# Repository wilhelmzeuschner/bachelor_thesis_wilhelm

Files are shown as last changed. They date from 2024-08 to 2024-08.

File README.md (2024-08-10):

# Bachelor Thesis Wilhelm Zeuschner
This repo contains select files of my bachelor thesis

More details can be found on my website where I wrote an article about my thesis.

www.wizeus.de/lmm-ba

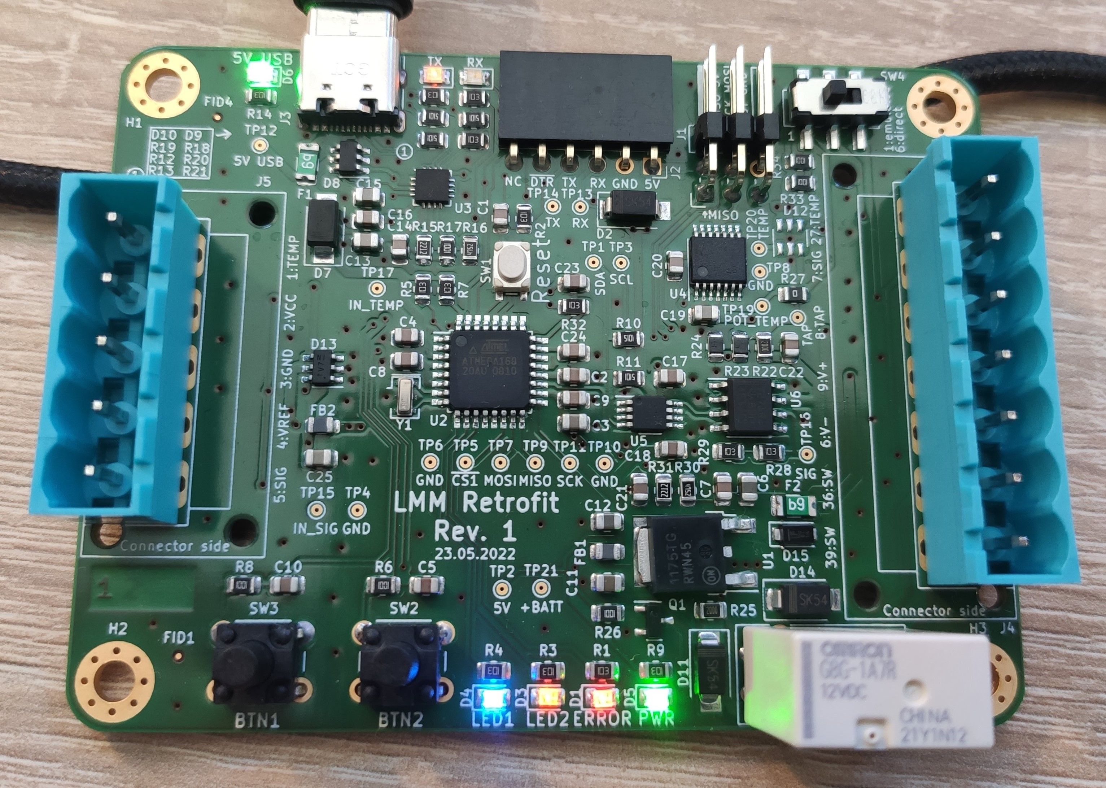
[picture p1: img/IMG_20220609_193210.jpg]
PCB picture


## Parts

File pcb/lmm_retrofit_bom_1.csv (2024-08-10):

Component | Description | Part | References | Value | Footprint | Quantity Per PCB | Datasheet | Digi-Key Part Number | MPN | Color | DNF | Info
1 | Unpolarized capacitor, small symbol | C_Small | C1 C2 C4 C5 C7 C8 C9 C10 C14 C16 C17 C18 C20 C21 C22 C23 C24 | 100nF | C_0805_2012Metric | 17 | https://www.yuden.co.jp/productdata/catalog/mlcc_all_hq_e.pdf | 587-3508-1-ND | UMK212B7104KGHT
2 | Unpolarized capacitor, small symbol | C_Small | C3 C6 C11 C12 C13 C15 C19 C25 | 10uF | C_0805_2012Metric | 8 | https://ds.yuden.co.jp/TYCOMPAS/ut/detail?pn=MCAST21GBB5106MTNA01&u=M | 587-6440-1-ND | TMK212BBJ106MGHT
3 | Light emitting diode, small symbol | LED_Small | D6 | 5V USB | LED_0805_2012Metric_Silkscreen_Text | 1 | https://www.we-online.com/katalog/datasheet/150080GS75000.pdf | 732-4983-1-ND | 150080GS75000 | Green
4 | Schottky diode, small symbol | D_Schottky_Small | D2 D7 D11 D14 | CDBA540-HF | D_SMA | 4 | https://media.digikey.com/pdf/Data%20Sheets/Comchip%20PDFs/CDBA540-HF-CDBA5200-HF_RevC.pdf | 641-1707-1-ND | CDBA540-HF
5 | 12V Clamp 3A (8/20µs) Ipp Tvs Diode Surface Mount SOT-26 | D5V0F4U6SO-7 | D12 D13 | D5V0F4U6SO-7 | SOT-23-6 | 2 | https://www.diodes.com/assets/Datasheets/D5V0F4U6SO.pdf | D5V0F4U6SO-7DICT-ND | D5V0F4U6SO-7
6 | 14V Clamp 7A (8/20µs) Ipp Tvs Diode Surface Mount SOT-26 | DM1231 | D8 | DM1231 | SOT-23-6 | 1 | https://media.digikey.com/pdf/Data%20Sheets/Diodes%20PDFs/DM1231-02SO.pdf | DM1231-02SO-7DICT-ND | DM1231-02SO-7
7 | Light emitting diode, small symbol | LED_Small | D1 | ERROR | LED_0805_2012Metric_Silkscreen_Text | 1 | https://www.we-online.com/katalog/datasheet/150080RS75000.pdf | 732-4984-1-ND | 150080RS75000 | Red
8 | Light emitting diode, small symbol | LED_Small | D4 | LED1 | LED_0805_2012Metric_Silkscreen_Text | 1 | https://www.we-online.com/katalog/datasheet/150080BS75000.pdf | 732-4982-1-ND | 150080BS75000 | Blue
9 | Light emitting diode, small symbol | LED_Small | D3 | LED2 | LED_0805_2012Metric_Silkscreen_Text | 1 | https://www.mouser.de/datasheet/2/445/150080AS75000-1879102.pdf | 732-150080AS75000CT-ND | 150080AS75000 | Amber
10 | Light emitting diode, small symbol | LED_Small | D5 | PWR | LED_0805_2012Metric_Silkscreen_Text | 1 | https://www.we-online.com/katalog/datasheet/150080GS75000.pdf | 732-4983-1-ND | 150080GS75000 | Green
11 | Light emitting diode, small symbol | LED_Small | D9 | RX | LED_0805_2012Metric_Silkscreen_Text | 1 | https://www.we-online.com/katalog/datasheet/150080BS75000.pdf | 732-4982-1-ND | 150080BS75000 | Blue
12 | Zener diode, small symbol | D_Zener_Small | D15 | SMF18A | D_SOD-123F | 1 | https://www.littelfuse.com/~/media/electronics/datasheets/tvs_diodes/littelfuse_tvs_diode_smf_datasheet.pdf.pdf | F5820CT-ND | SMF18A
13 | Light emitting diode, small symbol | LED_Small | D10 | TX | LED_0805_2012Metric_Silkscreen_Text | 1 | https://www.mouser.de/datasheet/2/445/150080AS75000-1879102.pdf | 732-150080AS75000CT-ND | 150080AS75000 | Amber
14 | Resettable fuse, polymeric positive temperature coefficient | Polyfuse | F1 F2 | 250mA | Fuse_1206_3216Metric | 2 | https://www.belfuse.com/resources/datasheets/circuitprotection/ds-cp-0zcj-series.pdf | 507-1799-1-ND | 0ZCJ0025AF2E
15 | Ferrite bead, small symbol | FerriteBead_Small | FB1 FB2 | 1k@100MHz | L_0805_2012Metric | 2 | https://abracon.com/Magnetics/new/ACML-0805.pdf | 535-ACML-0805-102-TCT-ND | ACML-0805-102-T
16 | Hot-film air-mass meter, Type HFM 5 | Bosch_HFM5_LMM | J5 | Bosch_HFM5_LMM | Bosch_Airmass_Senosor_5-Pin_Male_Blade_Connector | 1 | https://mux.hs-emden-leer.de/svn/micro-projects-lmm/30_datasheets/LMM/HFM5_Datenblatt.pdf |  | 0 280 217 531 |  | Do not fit
17 | Airflow meter for L Jetronic ECUs; Luftmengenmesser für Oldtimer | Bosch_old_LMM | J4 | Bosch_old_LMM | Bosch_L_Jetronic_7-Pin_Male_Blade_Conn | 1 | https://mux.hs-emden-leer.de/svn/micro-projects-lmm/30_datasheets/L_Jetronic/_tr7_ecu.pdf |  | 0 280 203 002 |  | Do not fit
18 | Generic connector, double row, 02x03, odd/even pin numbering scheme (row 1 odd numbers, row 2 even numbers), script generated (kicad-library-utils/schlib/autogen/connector/) | Conn_02x03_Odd_Even | J1 | ICSP | PinHeader_2x03_P2.54mm_Horizontal | 1 | https://app.adam-tech.com/products/download/data_sheet/200508/ph2ra-xx-ua-data-sheet.pdf | 2057-PH2RA-06-UA-ND | PH2RA-06-UA
19 | Generic connector, single row, 01x06, script generated (kicad-library-utils/schlib/autogen/connector/) | Conn_01x06_Female | J2 | PC | PinSocket_1x06_P2.54mm_Horizontal | 1 | https://media.metz-connect.com/files/171/Data_sheet_FR202XXHBNN.PDF | 1849-FR20206HBNN-ND | FR20206HBNN
20 | USB 2.0-only Type-C Receptacle connector | USB_C_Receptacle_USB2.0 | J3 | USB_C_Receptacle_USB2.0 | USB_C_Receptacle_GCT_USB4105-GF-A | 1 | https://gct.co/files/drawings/usb4105.pdf | 2073-USB4105-GF-ACT-ND | USB4105-GF-A
21 | AUTO MOTIVE PCB RELAY, DC 12V | G8G | K1 | G8G | G8G__SPST | 1 | https://components.omron.com/us-en/datasheet_pdf/J263-E1.pdf | 39-G8G-1A7RDC12BYOMR1-ND | G8G-1A7R DC12 BY OMR1
22 | NPN transistor, base/emitter/collector | Q_NPN_BEC | Q1 | MMBT4401-7-F | SOT-23 | 1 | https://www.comchiptech.com/admin/files/product/QW-JTR91%20MMBT4401-HF%20RevB.pdf | 641-MMBT4401-HFCT-ND | MMBT4401-HF
23 | Resistor, small symbol | R_Small | R27 | 0R | R_0805_2012Metric | 1 | https://www.yageo.com/upload/media/product/productsearch/datasheet/rchip/PYu-AC_51_RoHS_L_8.pdf | YAG3755CT-ND | AC0805JR-070RL |  |  | Populate with value >0R if voltage on A pin would be too high.
24 | Resistor, small symbol | R_Small | R23 R24 | 182 | R_0805_2012Metric | 2 | https://www.vishay.com/docs/20035/dcrcwe3.pdf | 541-182CCT-ND | CRCW0805182RFKEA
25 | Resistor, small symbol | R_Small | R22 R25 | 200 | R_0805_2012Metric | 2 | https://fscdn.rohm.com/en/products/databook/datasheet/passive/resistor/chip_resistor/esr-e.pdf | RHM200AECT-ND | ESR10EZPF2000
26 | Resistor, small symbol | R_Small | R6 R8 R17 R26 R33 R34 | 1k | R_0805_2012Metric | 6 | https://www.te.com/commerce/DocumentDelivery/DDEController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 | A129749CT-ND | CRGCQ0805F1K0
27 | Resistor, small symbol | R_Small | R10 R11 R12 R13 R20 | 5.1k | R_0805_2012Metric | 5 | https://www.te.com/commerce/DocumentDelivery/DDEController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 | A126379CT-ND | CRG0805F5K1
28 | Resistor, small symbol | R_Small | R1 R2 R3 R4 R5 R7 R9 R14 R18 R19 R21 R28 R29 R32 | 10k | R_0805_2012Metric | 14 | https://www.te.com/commerce/DocumentDelivery/DDEController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 | A130140CT-ND | CRGCQ0805J10K
29 | Resistor, small symbol | R_Small | R15 R31 | 22.1k | R_0805_2012Metric | 2 | https://www.bourns.com/docs/product-datasheets/cr.pdf?sfvrsn=574d41f6_14 | CR0805-FX-2212ELFCT-ND | CR0805-FX-2212ELF
30 | Resistor, small symbol | R_Small | R16 R30 | 47.5k | R_0805_2012Metric | 2 | https://www.bourns.com/docs/product-datasheets/cr.pdf?sfvrsn=574d41f6_14 | 118-CR0805-FX-4752ELFCT-ND | CR0805-FX-4752ELF
31 | Push button switch, generic, two pins | SW_Push | SW3 | BTN1 | SW_PUSH_6mm_H9.5mm | 1 | https://www.cuidevices.com/product/resource/ts03.pdf | 2223-TS03-66-95-BK-260-LCR-D-67-ND | TS03-66-95-BK-260-LCR-D-67
32 | Push button switch, generic, two pins | SW_Push | SW2 | BTN2 | SW_PUSH_6mm_H9.5mm | 1 | https://www.cuidevices.com/product/resource/ts03.pdf | 2223-TS03-66-95-BK-260-LCR-D-67-ND | TS03-66-95-BK-260-LCR-D-67
33 | Push button switch, four pins, both channels connected | CKN12216-1-ND | SW1 | Reset | PTS815_SMT_Push_Button | 1 | https://www.ckswitches.com/media/2728/pts815.pdf | CKN12216-1-ND | PTS815 SJK 250 SMTR LFS
34 | Switch, dual pole double throw, separate symbols | SW_DPDT_x2 | SW4 | Thermistor select | JS202011SCQN | 1 | https://www.ckswitches.com/media/1422/js.pdf | 401-2002-1-ND | JS202011SCQN
35 | Digital potentiometer, 256 position, single output, I2C interface | AD5280 | U4 | AD5280 | TSSOP-14_4.4x5mm_P0.65mm | 1 | https://www.analog.com/media/en/technical-documentation/data-sheets/AD5280_5282.pdf | AD5280BRUZ50-ND | AD5280BRUZ50
36 | 20MHz, 16kB Flash, 1kB SRAM, 512B EEPROM, TQFP-32 | ATmega168-20A | U2 | ATmega168-20A | TQFP-32_7x7mm_P0.8mm | 1 | http://ww1.microchip.com/downloads/en/DeviceDoc/Atmel-2545-8-bit-AVR-Microcontroller-ATmega48-88-168_Datasheet.pdf | ATMEGA168-20AU-ND | ATMEGA168-20AU
37 | USB to UART master bridge, QFN-20 | CP2102N-Axx-xQFN20 | U3 | CP2102N-A02-GQFN20 | SiliconLabs_QFN-20-1EP_3x3mm_P0.5mm_EP1.8x1.8mm_Center_Via | 1 | https://www.silabs.com/documents/public/data-sheets/cp2102n-datasheet.pdf | 336-5885-ND | CP2102N-A02-GQFN20
38 | 10 Bit Digital to Analog Converter 1 8-VSSOP | DAC101C085CIMM{slash}NOPB | U5 | DAC101C085CIMM/NOPB | VSSOP-8_3.0x3.0mm_P0.65mm | 1 | http://www.ti.com/lit/ds/symlink/dac101c081.pdf | DAC101C085CIMM/NOPBCT-ND | DAC101C085CIMM/NOPB
39 | 1A Low drop-out regulator, Fixed Output 5.0V, TO-252 (DPAK) | NCP1117-5.0_TO252 | U1 | NCP1117IDT50T4G | TO-252-2 | 1 | https://www.onsemi.com/pdf/datasheet/ncp1117-d.pdf | 488-NCP1117IDT50T4GCT-ND | NCP1117IDT50T4G
40 | General Purpose Amplifier 1 Circuit Rail-to-Rail 8-SOIC | TLV271 | U6 | TLV271 | SOIC-8_3.9x4.9mm_P1.27mm | 1 | https://www.ti.com/general/docs/suppproductinfo.tsp?distId=10 | 296-38281-1-ND | TLV271QDRQ1
41 | Three pin ceramic resonator, small symbol | Resonator_Small | Y1 | 16MHz | Resonator_SMD_Murata_CSTxExxV-3Pin_3.0x1.1mm | 1 | https://www.murata.com/en/products/productdata/8801162231838/SPEC-CSTNE16M0V530000R0.pdf | 490-17948-1-ND | CSTNE16M0V530000R0
Component Groups: | 41
Component Count: | 96
Fitted Components: | 96
Number of PCBs: | 1
Total components: | 96
Schematic Version: | 1
Schematic Date: | 2022-05-08
PCB Variant: | default
BoM Date: | 22/05/2022 21:42:45
Schematic Source: | lmm_retrofit.kicad_sch
KiCad Version: | Eeschema (6.0.5)

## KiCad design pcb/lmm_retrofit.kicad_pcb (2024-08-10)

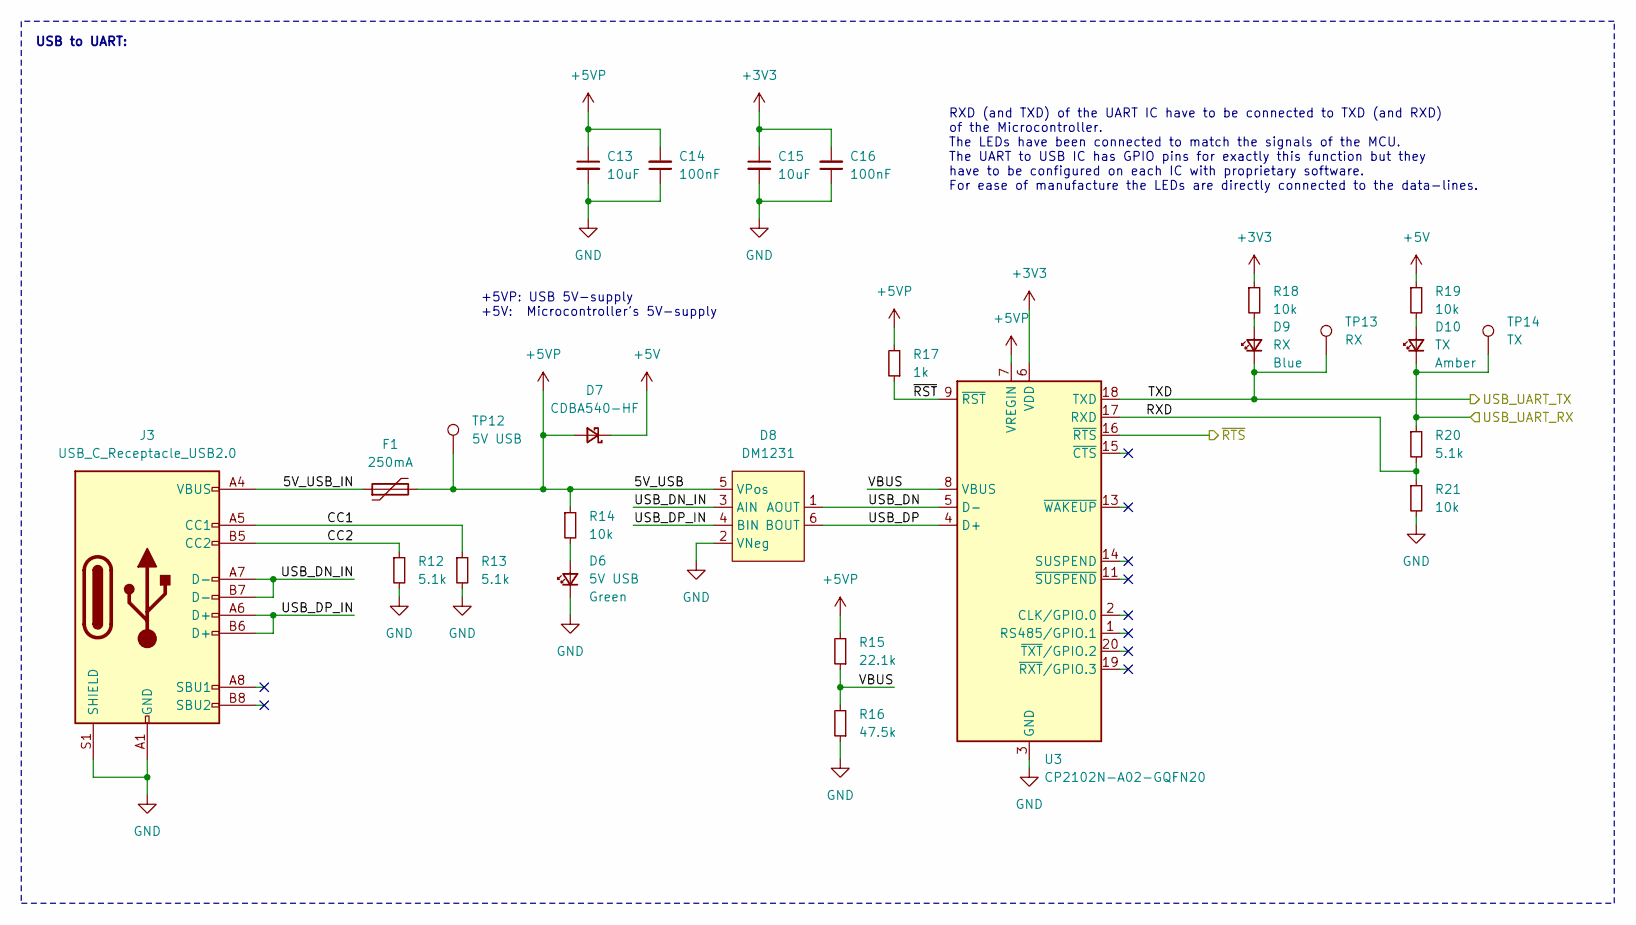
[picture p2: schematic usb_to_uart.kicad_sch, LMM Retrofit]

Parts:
C13, C15: 10uF; C_0805_2012Metric; MPN TMK212BBJ106MGHT; Digi-Key Part Number 587-6440-1-ND
C14, C16: 100nF; C_0805_2012Metric; MPN UMK212B7104KGHT; Digi-Key Part Number 587-3508-1-ND
D6: 5V USB; LED_0805_2012Metric_Silkscreen_Text; MPN 150080GS75000; Digi-Key Part Number 732-4983-1-ND
D7: CDBA540-HF; D_SMA; MPN CDBA540-HF; Digi-Key Part Number 641-1707-1-ND
D8: DM1231; SOT-23-6; MPN DM1231-02SO-7; Digi-Key Part Number DM1231-02SO-7DICT-ND
D9: RX; LED_0805_2012Metric_Silkscreen_Text; MPN 150080BS75000; Digi-Key Part Number 732-4982-1-ND
D10: TX; LED_0805_2012Metric_Silkscreen_Text; MPN 150080AS75000; Digi-Key Part Number 732-150080AS75000CT-ND
F1: 250mA; Fuse_1206_3216Metric; MPN 0ZCJ0025AF2E; Digi-Key Part Number 507-1799-1-ND
J3: USB_C_Receptacle_USB2.0; USB_C_Receptacle_GCT_USB4105-GF-A; MPN USB4105-GF-A; Digi-Key Part Number 2073-USB4105-GF-ACT-ND
R12, R13, R20: 5.1k; R_0805_2012Metric; MPN CRG0805F5K1; Digi-Key Part Number A126379CT-ND
R14, R18, R19, R21: 10k; R_0805_2012Metric; MPN CRGCQ0805J10K; Digi-Key Part Number A130140CT-ND
R15: 22.1k; R_0805_2012Metric; MPN CR0805-FX-2212ELF; Digi-Key Part Number CR0805-FX-2212ELFCT-ND
R16: 47.5k; R_0805_2012Metric; MPN CR0805-FX-4752ELF; Digi-Key Part Number 118-CR0805-FX-4752ELFCT-ND
R17: 1k; R_0805_2012Metric; MPN CRGCQ0805F1K0; Digi-Key Part Number A129749CT-ND
TP12: 5V USB; TestPoint_Pad_D1.0mm_Text_Silkscreen
TP13: RX; TestPoint_Pad_D1.0mm_Text_Silkscreen
TP14: TX; TestPoint_Pad_D1.0mm_Text_Silkscreen
U3: CP2102N-A02-GQFN20; SiliconLabs_QFN-20-1EP_3x3mm_P0.5mm_EP1.8x1.8mm_Center_Via; MPN CP2102N-A02-GQFN20; Digi-Key Part Number 336-5885-ND

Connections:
+3V3: C15.1, C16.2, R18.1, U3.6 (VDD)
+5V: D7.1 (K), R19.1; also elsewhere on the board
+5VP: C13.1, C14.2, D7.2 (A), D8.5 (VPos), F1.2, R14.1, R15.2, R17.2, TP12.1, U3.7 (VREGIN)
/Microcontroller/D0/UART_RX: D9.1 (K), TP13.1, U3.18 (TXD); also elsewhere on the board
/Microcontroller/D1/UART_TX: D10.1 (K), R20.1, TP14.1; also elsewhere on the board
/Microcontroller/~DTR: U3.16 (~RTS); also elsewhere on the board
/USB to UART/5V_USB_IN: F1.1, J3.A4 (VBUS), J3.A9 (VBUS), J3.B4 (VBUS), J3.B9 (VBUS)
/USB to UART/CC1: J3.A5 (CC1), R13.1
/USB to UART/CC2: J3.B5 (CC2), R12.1
/USB to UART/RXD: R20.2, R21.1, U3.17 (RXD)
/USB to UART/USB_DN: D8.1 (AOUT), U3.5 (D-)
/USB to UART/USB_DN_IN: D8.3 (AIN), J3.A7 (D-), J3.B7 (D-)
/USB to UART/USB_DP: D8.6 (BOUT), U3.4 (D+)
/USB to UART/USB_DP_IN: D8.4 (BIN), J3.A6 (D+), J3.B6 (D+)
/USB to UART/VBUS: R15.1, R16.2, U3.8 (VBUS)
/USB to UART/~RST: R17.1, U3.9 (~RST)
unnamed: D6.2 (A), R14.2
unnamed: D9.2 (A), R18.2
unnamed: D10.2 (A), R19.2

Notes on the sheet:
+5VP: USB 5V-supply +5V: Microcontroller's 5V-supply
USB to UART:
RXD (and TXD) of the UART IC have to be connected to TXD (and RXD) of the Microcontroller. The LEDs have been connected to match the signals of the MCU. The UART to USB IC has GPIO pins for exactly this function but they have to be configured on each IC with proprietary software. For ease of manufa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

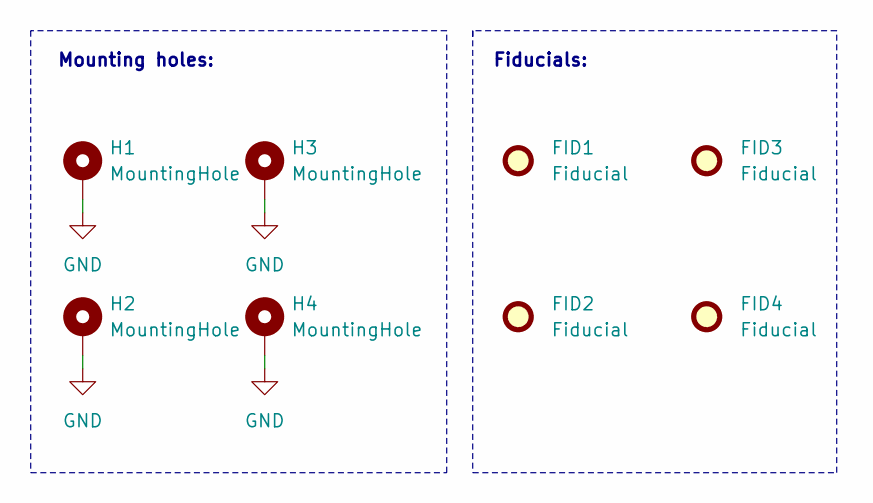
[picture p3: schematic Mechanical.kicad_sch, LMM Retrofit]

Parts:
FID1, FID2, FID3, FID4: Fiducial; Fiducial_0.5mm_Mask1mm
H1, H2, H3, H4: MountingHole; MountingHole_3.2mm_M3_Pad_Via

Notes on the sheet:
Fiducials:
Mounting holes:

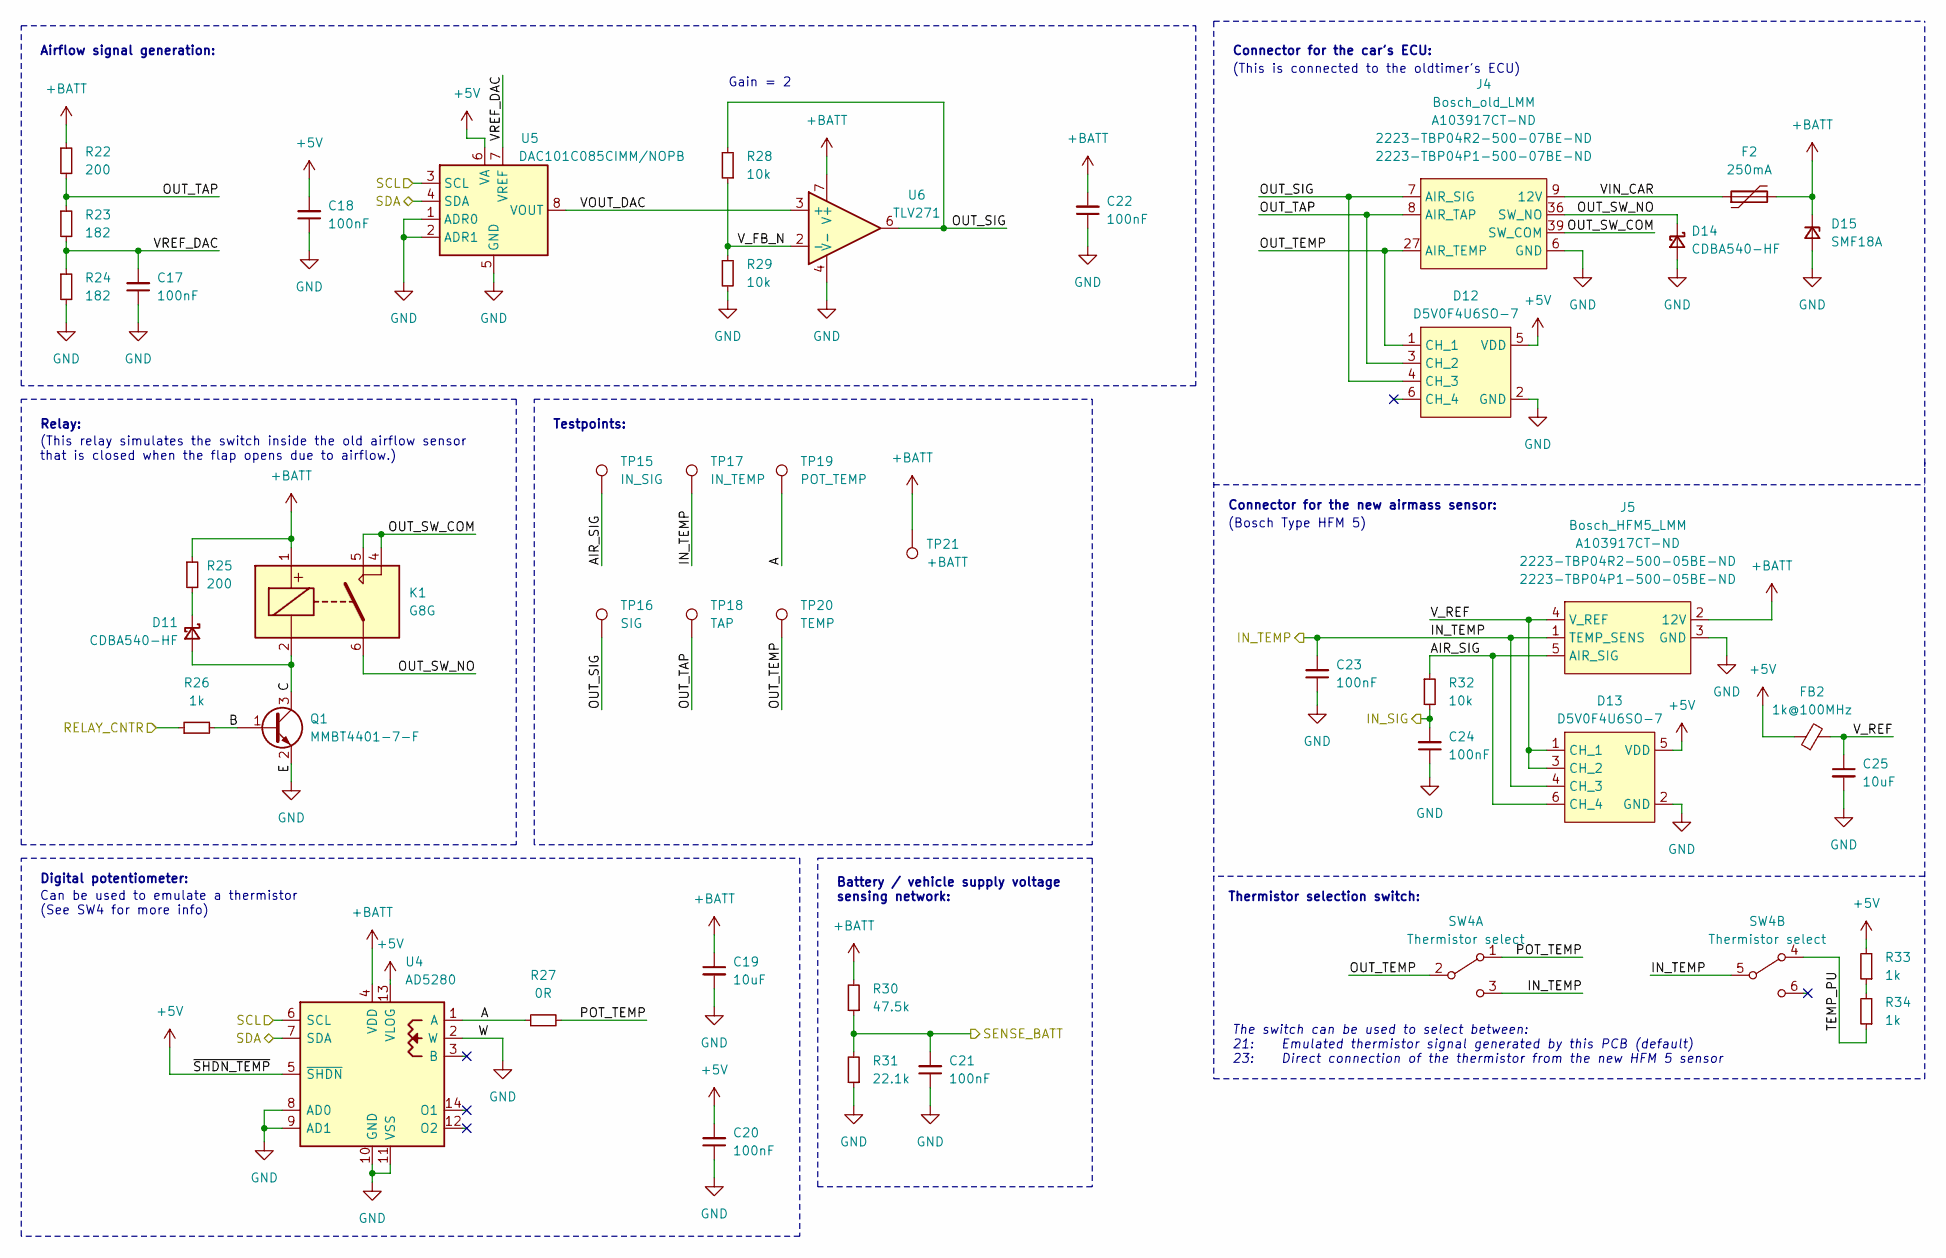
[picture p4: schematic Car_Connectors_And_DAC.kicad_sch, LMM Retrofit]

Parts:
C17, C18, C20, C21, C22, C23, C24: 100nF; C_0805_2012Metric; MPN UMK212B7104KGHT; Digi-Key Part Number 587-3508-1-ND
C19, C25: 10uF; C_0805_2012Metric; MPN TMK212BBJ106MGHT; Digi-Key Part Number 587-6440-1-ND
D11, D14: CDBA540-HF; D_SMA; MPN CDBA540-HF; Digi-Key Part Number 641-1707-1-ND
D12, D13: D5V0F4U6SO-7; SOT-23-6; MPN D5V0F4U6SO-7; Digi-Key Part Number D5V0F4U6SO-7DICT-ND
D15: SMF18A; D_SOD-123F; MPN SMF18A; Digi-Key Part Number F5820CT-ND
F2: 250mA; Fuse_1206_3216Metric; MPN 0ZCJ0025AF2E; Digi-Key Part Number 507-1799-1-ND
FB2: 1k@100MHz; L_0805_2012Metric; MPN ACML-0805-102-T; Digi-Key Part Number 535-ACML-0805-102-TCT-ND
J4: Bosch_old_LMM; Bosch_L_Jetronic_7-Pin_Male_Blade_Conn; MPN 0 280 203 002
J5: Bosch_HFM5_LMM; Bosch_Airmass_Senosor_5-Pin_Male_Blade_Connector; MPN 0 280 217 531
K1: G8G; G8G__SPST; MPN G8G-1A7R DC12 BY OMR1; Digi-Key Part Number 39-G8G-1A7RDC12BYOMR1-ND
Q1: MMBT4401-7-F; SOT-23; MPN MMBT4401-HF; Digi-Key Part Number 641-MMBT4401-HFCT-ND
R22, R25: 200; R_0805_2012Metric; MPN ESR10EZPF2000; Digi-Key Part Number RHM200AECT-ND
R23, R24: 182; R_0805_2012Metric; MPN CRCW0805182RFKEA; Digi-Key Part Number 541-182CCT-ND
R26, R33, R34: 1k; R_0805_2012Metric; MPN CRGCQ0805F1K0; Digi-Key Part Number A129749CT-ND
R27: 0R; R_0805_2012Metric; MPN AC0805JR-070RL; Digi-Key Part Number YAG3755CT-ND
R28, R29, R32: 10k; R_0805_2012Metric; MPN CRGCQ0805J10K; Digi-Key Part Number A130140CT-ND
R30: 47.5k; R_0805_2012Metric; MPN CR0805-FX-4752ELF; Digi-Key Part Number 118-CR0805-FX-4752ELFCT-ND
R31: 22.1k; R_0805_2012Metric; MPN CR0805-FX-2212ELF; Digi-Key Part Number CR0805-FX-2212ELFCT-ND
SW4: Thermistor select; JS202011SCQN; MPN JS202011SCQN; Digi-Key Part Number 401-2002-1-ND
TP15: IN_SIG; TestPoint_Pad_D1.0mm_Text_Silkscreen
TP16: SIG; TestPoint_Pad_D1.0mm_Text_Silkscreen
TP17: IN_TEMP; TestPoint_Pad_D1.0mm_Text_Silkscreen
TP18: TAP; TestPoint_Pad_D1.0mm_Text_Silkscreen
TP19: POT_TEMP; TestPoint_Pad_D1.0mm_Text_Silkscreen
TP20: TEMP; TestPoint_Pad_D1.0mm_Text_Silkscreen
TP21: +BATT; TestPoint_Pad_D1.0mm_Text_Silkscreen
U4: AD5280; TSSOP-14_4.4x5mm_P0.65mm; MPN AD5280BRUZ50; Digi-Key Part Number AD5280BRUZ50-ND
U5: DAC101C085CIMM/NOPB; VSSOP-8_3.0x3.0mm_P0.65mm; MPN DAC101C085CIMM/NOPB; Digi-Key Part Number DAC101C085CIMM/NOPBCT-ND
U6: TLV271; SOIC-8_3.9x4.9mm_P1.27mm; MPN TLV271QDRQ1; Digi-Key Part Number 296-38281-1-ND

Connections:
+5V: C18.2, C20.2, D12.5 (VDD), D13.5 (VDD), FB2.1, R33.2, U4.5 (~SHDN), U4.13 (VLOG), U5.6 (VA); also elsewhere on the board
+BATT: C19.1, C22.2, D15.1 (K), F2.2, J5.2 (12V), K1.1, R22.1, R25.1, R30.2, TP21.1, U4.4 (VDD), U6.7 (V+); also elsewhere on the board
/Car_Connectors_And_DAC/A: R27.1, TP19.1, U4.1 (A)
/Car_Connectors_And_DAC/AIR_SIG: D13.6 (CH_4), J5.5 (AIR_SIG), R32.1, TP15.1
/Car_Connectors_And_DAC/B: Q1.1 (B), R26.2
/Car_Connectors_And_DAC/C: D11.2 (A), K1.2, Q1.3 (C)
/Car_Connectors_And_DAC/IN_TEMP: C23.2, D13.4 (CH_3), J5.1 (TEMP_SENS), SW4.3 (C), SW4.5 (B), TP17.1; also elsewhere on the board
/Car_Connectors_And_DAC/OUT_SIG: D12.4 (CH_3), J4.7 (AIR_SIG), R28.2, TP16.1, U6.6
/Car_Connectors_And_DAC/OUT_SW_COM: J4.39 (SW_COM), K1.4, K1.5
/Car_Connectors_And_DAC/OUT_SW_NO: D14.1 (K), J4.36 (SW_NO), K1.6
/Car_Connectors_And_DAC/OUT_TAP: D12.3 (CH_2), J4.8 (AIR_TAP), R22.2, R23.1, TP18.1
/Car_Connectors_And_DAC/OUT_TEMP: D12.1 (CH_1), J4.27 (AIR_TEMP), SW4.2 (B), TP20.1
/Car_Connectors_And_DAC/POT_TEMP: R27.2, SW4.1 (A)
/Car_Connectors_And_DAC/TEMP_PU: R34.1, SW4.4 (A)
/Car_Connectors_And_DAC/VIN_CAR: F2.1, J4.9 (12V)
/Car_Connectors_And_DAC/VOUT_DAC: U5.8 (VOUT), U6.3 (+)
/Car_Connectors_And_DAC/VREF_DAC: C17.2, R23.2, R24.1, U5.7 (VREF)
/Car_Connectors_And_DAC/V_FB_N: R28.1, R29.1, U6.2 (-)
/Car_Connectors_And_DAC/V_REF: C25.1, D13.1 (CH_1), D13.3 (CH_2), FB2.2, J5.4 (V_REF)
/Microcontroller/A0/SIG: C24.2, R32.2; also elsewhere on the board
/Microcontroller/A4/SDA: U4.7 (SDA), U5.4 (SDA); also elsewhere on the board
/Microcontroller/A5/SCL: U4.6 (SCL), U5.3 (SCL); also elsewhere on the board
/Microcontroller/A6/BATT: C21.2, R30.1, R31.2; also elsewhere on the board
/Microcontroller/D4/RELAY: R26.1; also elsewhere on the board
unnamed: D11.1 (K), R25.2
unnamed: R33.1, R34.2

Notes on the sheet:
Testpoints:
Battery / vehicle supply voltage sensing network:
Connector for the car's ECU:
The switch can be used to select between: 21: Emulated thermistor signal generated by this PCB (default) 23: Direct connection of the thermistor from the new HFM 5 sensor
Digital potentiometer:
Thermistor selection switch:
(Bosch Type HFM 5)
Relay:
Airflow signal generation:
Connector for the new airmass sensor:
Gain = 2
(This relay simulates the switch inside the old airflow sensor that is closed when the flap opens due to airflow.)
(This is connected to the oldtimer's ECU)
Can be used to emulate a thermistor (See SW4 for more info)

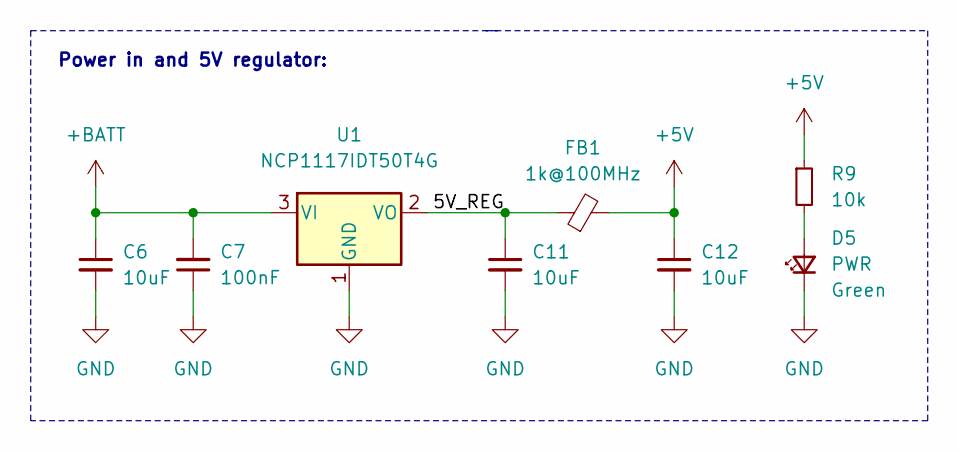
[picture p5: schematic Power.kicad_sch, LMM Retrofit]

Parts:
C6, C11, C12: 10uF; C_0805_2012Metric; MPN TMK212BBJ106MGHT; Digi-Key Part Number 587-6440-1-ND
C7: 100nF; C_0805_2012Metric; MPN UMK212B7104KGHT; Digi-Key Part Number 587-3508-1-ND
D5: PWR; LED_0805_2012Metric_Silkscreen_Text; MPN 150080GS75000; Digi-Key Part Number 732-4983-1-ND
FB1: 1k@100MHz; L_0805_2012Metric; MPN ACML-0805-102-T; Digi-Key Part Number 535-ACML-0805-102-TCT-ND
R9: 10k; R_0805_2012Metric; MPN CRGCQ0805J10K; Digi-Key Part Number A130140CT-ND
U1: NCP1117IDT50T4G; TO-252-2; MPN NCP1117IDT50T4G; Digi-Key Part Number 488-NCP1117IDT50T4GCT-ND

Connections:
+5V: C12.1, FB1.2, R9.1; also elsewhere on the board
+BATT: C6.1, C7.2, U1.3 (VI); also elsewhere on the board
/Power/5V_REG: C11.1, FB1.1, U1.2 (VO)
unnamed: D5.2 (A), R9.2

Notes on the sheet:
Power in and 5V regulator:

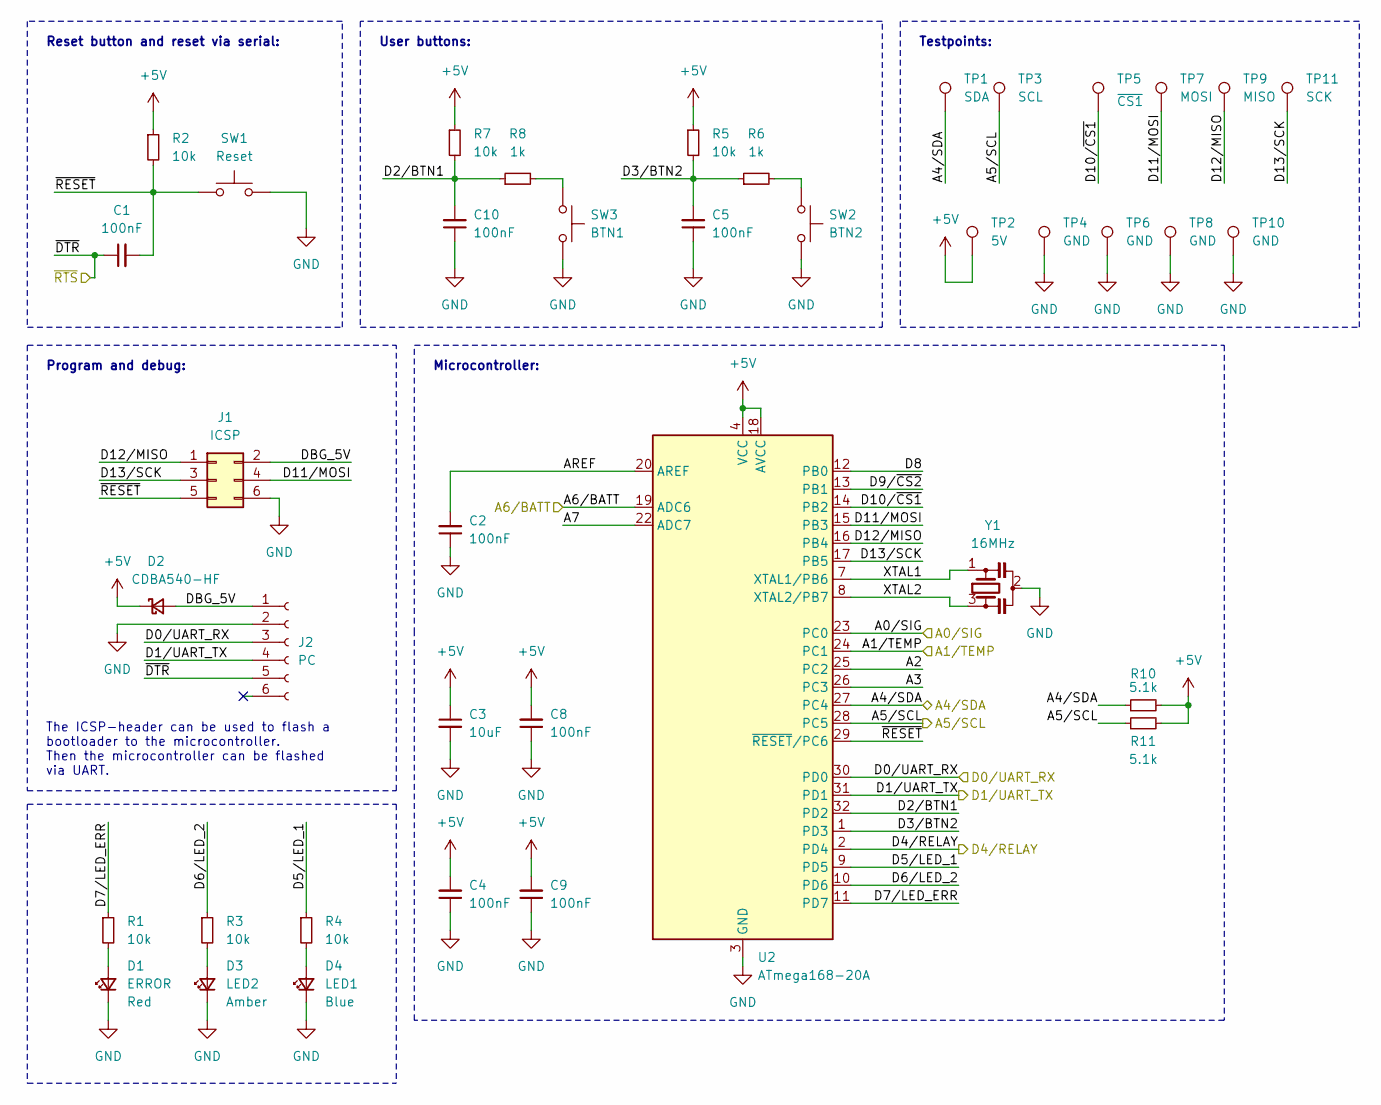
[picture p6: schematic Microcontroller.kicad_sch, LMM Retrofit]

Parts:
C1, C2, C4, C5, C8, C9, C10: 100nF; C_0805_2012Metric; MPN UMK212B7104KGHT; Digi-Key Part Number 587-3508-1-ND
C3: 10uF; C_0805_2012Metric; MPN TMK212BBJ106MGHT; Digi-Key Part Number 587-6440-1-ND
D1: ERROR; LED_0805_2012Metric_Silkscreen_Text; MPN 150080RS75000; Digi-Key Part Number 732-4984-1-ND
D2: CDBA540-HF; D_SMA; MPN CDBA540-HF; Digi-Key Part Number 641-1707-1-ND
D3: LED2; LED_0805_2012Metric_Silkscreen_Text; MPN 150080AS75000; Digi-Key Part Number 732-150080AS75000CT-ND
D4: LED1; LED_0805_2012Metric_Silkscreen_Text; MPN 150080BS75000; Digi-Key Part Number 732-4982-1-ND
J1: ICSP; PinHeader_2x03_P2.54mm_Horizontal; MPN PH2RA-06-UA; Digi-Key Part Number 2057-PH2RA-06-UA-ND
J2: PC; PinSocket_1x06_P2.54mm_Horizontal; MPN FR20206HBNN; Digi-Key Part Number 1849-FR20206HBNN-ND
R1, R2, R3, R4, R5, R7: 10k; R_0805_2012Metric; MPN CRGCQ0805J10K; Digi-Key Part Number A130140CT-ND
R6, R8: 1k; R_0805_2012Metric; MPN CRGCQ0805F1K0; Digi-Key Part Number A129749CT-ND
R10, R11: 5.1k; R_0805_2012Metric; MPN CRG0805F5K1; Digi-Key Part Number A126379CT-ND
SW1: Reset; PTS815_SMT_Push_Button; MPN PTS815 SJK 250 SMTR LFS; Digi-Key Part Number CKN12216-1-ND
SW2: BTN2; SW_PUSH_6mm_H9.5mm; MPN TS03-66-95-BK-260-LCR-D-67; Digi-Key Part Number 2223-TS03-66-95-BK-260-LCR-D-67-ND
SW3: BTN1; SW_PUSH_6mm_H9.5mm; MPN TS03-66-95-BK-260-LCR-D-67; Digi-Key Part Number 2223-TS03-66-95-BK-260-LCR-D-67-ND
TP1: SDA; TestPoint_Pad_D1.0mm_Text_Silkscreen
TP2: 5V; TestPoint_Pad_D1.0mm_Text_Silkscreen
TP3: SCL; TestPoint_Pad_D1.0mm_Text_Silkscreen
TP4, TP6, TP8, TP10: GND; TestPoint_Pad_D1.0mm_Text_Silkscreen
TP5: ~{CS1}; TestPoint_Pad_D1.0mm_Text_Silkscreen
TP7: MOSI; TestPoint_Pad_D1.0mm_Text_Silkscreen
TP9: MISO; TestPoint_Pad_D1.0mm_Text_Silkscreen
TP11: SCK; TestPoint_Pad_D1.0mm_Text_Silkscreen
U2: ATmega168-20A; TQFP-32_7x7mm_P0.8mm; MPN ATMEGA168-20AU; Digi-Key Part Number ATMEGA168-20AU-ND
Y1: 16MHz; Resonator_SMD_Murata_CSTxExxV-3Pin_3.0x1.1mm; MPN CSTNE16M0V530000R0; Digi-Key Part Number 490-17948-1-ND

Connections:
+5V: C3.1, C4.2, C8.2, C9.2, D2.1 (K), R2.1, R5.1, R7.1, R10.2, R11.2, TP2.1, U2.4 (VCC), U2.6 (VCC), U2.18 (AVCC); also elsewhere on the board
/Car_Connectors_And_DAC/IN_TEMP: U2.24 (PC1); also elsewhere on the board
/Microcontroller/A0/SIG: U2.23 (PC0); also elsewhere on the board
/Microcontroller/A2: U2.25 (PC2)
/Microcontroller/A3: U2.26 (PC3)
/Microcontroller/A4/SDA: R10.1, TP1.1, U2.27 (PC4); also elsewhere on the board
/Microcontroller/A5/SCL: R11.1, TP3.1, U2.28 (PC5); also elsewhere on the board
/Microcontroller/A6/BATT: U2.19 (ADC6); also elsewhere on the board
/Microcontroller/A7: U2.22 (ADC7)
/Microcontroller/AREF: C2.2, U2.20 (AREF)
/Microcontroller/D0/UART_RX: J2.3, U2.30 (PD0); also elsewhere on the board
/Microcontroller/D1/UART_TX: J2.4, U2.31 (PD1); also elsewhere on the board
/Microcontroller/D2/BTN1: C10.2, R7.2, R8.1, U2.32 (PD2)
/Microcontroller/D3/BTN2: C5.2, R5.2, R6.1, U2.1 (PD3)
/Microcontroller/D4/RELAY: U2.2 (PD4); also elsewhere on the board
/Microcontroller/D5/LED_1: R4.1, U2.9 (PD5)
/Microcontroller/D6/LED_2: R3.1, U2.10 (PD6)
/Microcontroller/D7/LED_ERR: R1.1, U2.11 (PD7)
/Microcontroller/D8: U2.12 (PB0)
/Microcontroller/D9/~CS2: U2.13 (PB1)
/Microcontroller/D10/~CS1: TP5.1, U2.14 (PB2)
/Microcontroller/D11/MOSI: J1.4, TP7.1, U2.15 (PB3)
/Microcontroller/D12/MISO: J1.1, TP9.1, U2.16 (PB4)
/Microcontroller/D13/SCK: J1.3, TP11.1, U2.17 (PB5)
/Microcontroller/DBG_5V: D2.2 (A), J1.2, J2.1
/Microcontroller/XTAL1: U2.7 (XTAL1/PB6), Y1.1
/Microcontroller/XTAL2: U2.8 (XTAL2/PB7), Y1.3
/Microcontroller/~DTR: C1.1, J2.5; also elsewhere on the board
/Microcontroller/~RESET: C1.2, J1.5, R2.2, SW1.1, SW1.2, U2.29 (~RESET/PC6)
unnamed: D1.2 (A), R1.2
unnamed: D3.2 (A), R3.2
unnamed: D4.2 (A), R4.2
unnamed: R6.2, SW2.1
unnamed: R8.2, SW3.1

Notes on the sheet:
Reset button and reset via serial:
User buttons:
Program and debug:
Testpoints:
The ICSP-header can be used to flash a bootloader to the microcontroller. Then the microcontroller can be flashed via UART.
Microcontroller:

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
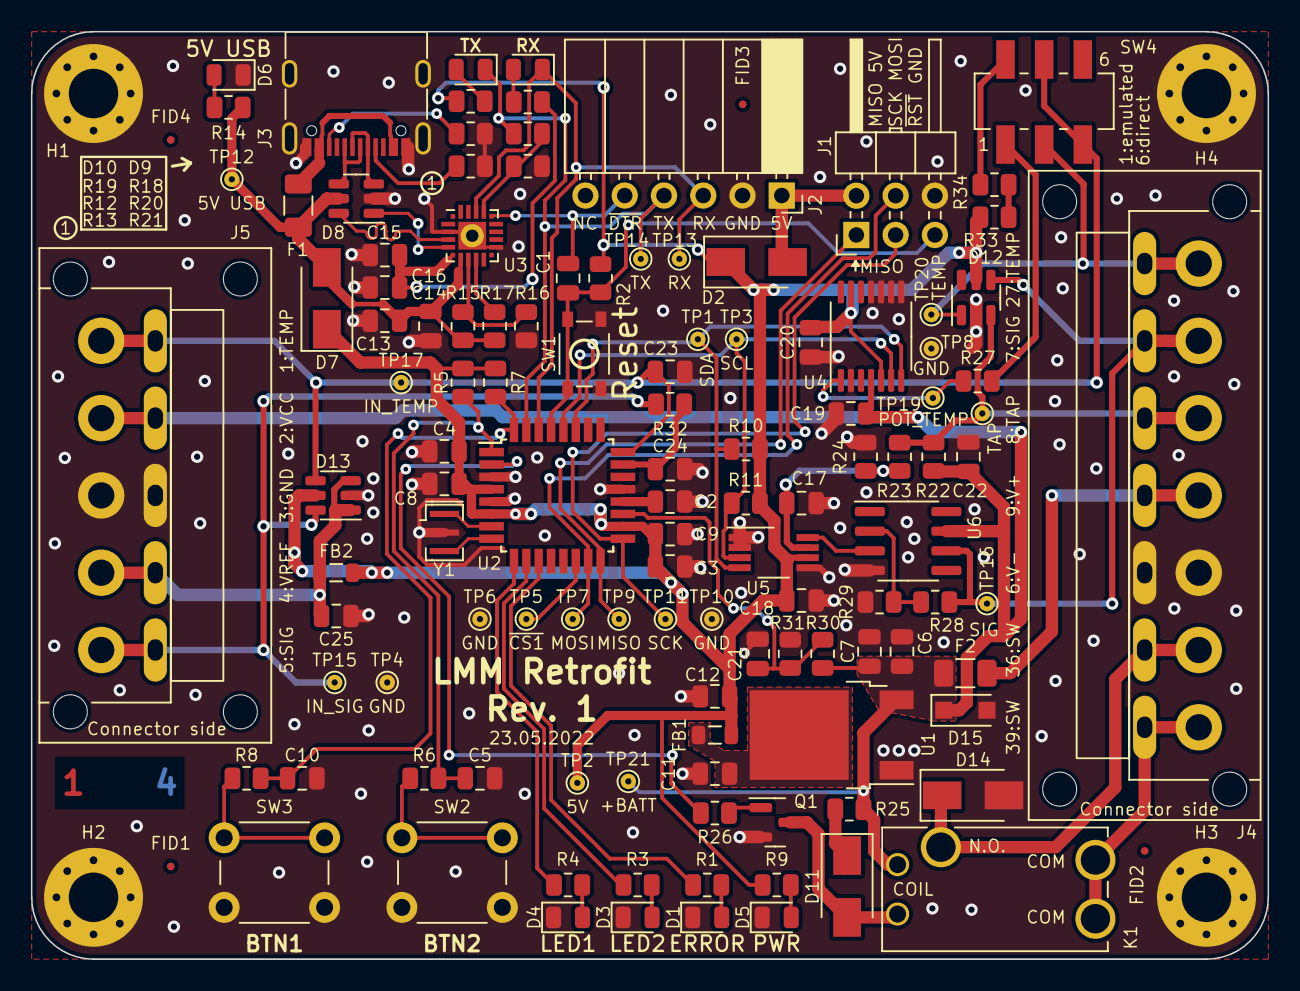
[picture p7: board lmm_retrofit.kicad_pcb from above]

Board: 4 copper layers, 80.0 x 60.0 mm, 125 parts (0 on the bottom side), 66 nets.

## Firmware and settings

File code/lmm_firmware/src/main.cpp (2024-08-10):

/*
This file is part of the LMM-Retrofit project.

Created on: 09. Jun 2022
Author: Hans Wilhelm Zeuschner

Bachelorarbeit:
	"Retrofit eines modernen
	Luftmassenmessers in einen Ottomotor
	mit Bosch L-Jetronic ECU unter
	Verwendung eines Mikrocontrollers"


Fachhochschule Emden/Leer

Studiengang:
Elektrotechnik im Praxisverbund
Sommersemester 2022
Bearbeitungszeitraum: 14.04.2022 bis 22.07.2022

Betreuer: Prof. Dr. Carsten Koch
Zweitprüfer: B. Eng. Ewald Zimmermann
*/

#include <Arduino.h>
#include <Wire.h>
#include <EEPROM.h>
#include <avr/wdt.h>

#include "lmm_pins.h"
#include "lmm_basic_io.h"
#include "lmm_uart_config.h"
#include "lmm_dac_sig.h"
#include "lmm_digi_pot.h"
#include "lmm_electronic_sensor.h"
#include "lmm_config.h"

/*
 *  \mainpage LMM-Retrofit Firmware
 *
 *  <HR>
 *
 *  \section sec1 Overview
 *
 *  <HR>
 *
 *   \author	Hans Wilhelm Zeuschner
 *   \date		19.06.2022
 *   \version 	1
 */

// Global variables
volatile uint8_t btnPressState = 0;

void setup()
{
	uint8_t ledState = 0;
	uint16_t airADCVal = 0;
	uint8_t activeLMMSlot = EEPROM.read(CONFIG_EEPROM_SLOT_ADDR);

	unsigned int timer = 0;

	volatile unsigned int runtimeCounter = 0;

	Wire.begin();
	wdt_enable(WDTO_15MS); // Initialize watchdog timer to trip after 15ms
	initIOPins();
	initUART(&activeLMMSlot);
	setLEDs(&ledState); // Turn LEDs off

	// Main program loop
	while (1)
	{
		runtimeCounter++;
		wdt_reset(); // Reset watchdog timer

		checkForLMMErrors(&ledState);

		readElectrSensAir(&airADCVal);

		// Serial.println(airADCVal);
		setSIGVoltage(calcSIGVoltageFromADC(&airADCVal, &activeLMMSlot));

		handleButtons(&activeLMMSlot, &ledState);
		setRelay(&airADCVal);

		if (runtimeCounter == 1000)
		{
			runtimeCounter = 0;
			// Toggle Pin D13
			digitalWrite(13, !digitalRead(13));
		}
	}
}

// Loop is not used since it's slightly slower than a while() loop
void loop()
{
}

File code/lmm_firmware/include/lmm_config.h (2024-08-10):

/*
This file is part of the LMM-Retrofit project.

Created on: 09. Jun 2022
Author: Hans Wilhelm Zeuschner

Bachelorarbeit:
	"Retrofit eines modernen
	Luftmassenmessers in einen Ottomotor
	mit Bosch L-Jetronic ECU unter
	Verwendung eines Mikrocontrollers"


Fachhochschule Emden/Leer

Studiengang:
Elektrotechnik im Praxisverbund
Sommersemester 2022
Bearbeitungszeitraum: 14.04.2022 bis 22.07.2022

Betreuer: Prof. Dr. Carsten Koch
Zweitprüfer: B. Eng. Ewald Zimmermann
*/

#ifndef LMM_CONFIG__
#define LMM_CONFIG__


//Battery (supply) voltage measurement
//Resistor values (the absolute value isn't important, the ratio matters!)
#define CONFIG_R1_VBATT						475
#define CONFIG_R2_VBATT						221

#define CONFIG_ADC_MAX						1023
#define CONFIG_VBATT_AVG_COUNT				2				//Sets how many measurements are made and averaged

#define CONFIG_TEMPERATURE_AVG_COUNT		1				//Sets how many measurements are made and averaged

#define CONFIG_AIR_SENS_AVG_COUNT			8				//Sets how many measurements are made and averaged


#define CONFIG_VBATT_NOMINAL_MILLIVOLT				12000	//Nominal battery voltage in mV
#define CONFIG_VBATT_ACCEPTABLE_DEVIATON_PERCENT	0.3		//How may percent is the battery voltage allowed to deviate from the nominal 12 V before it gets regarded as an issue


#define CONFIG_VBATT_NOMINAL_LOWER			(int)(CONFIG_VBATT_NOMINAL_MILLIVOLT * (1 - CONFIG_VBATT_ACCEPTABLE_DEVIATON_PERCENT))
#define CONFIG_VBATT_NOMINAL_UPPER			(int)(CONFIG_VBATT_NOMINAL_MILLIVOLT * (1 + CONFIG_VBATT_ACCEPTABLE_DEVIATON_PERCENT))

#define CONFIG_ERR_LED_BLINK_INTERVAL		500

#define CONFIG_EEPROM_SLOT_ADDR				0x0


#define CONFIG_RELAY_ADC_ON_VAL				280
#define CONFIG_RELAY_HYSTERESIS				50

#endif

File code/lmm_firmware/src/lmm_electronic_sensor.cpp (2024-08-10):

/*
This file is part of the LMM-Retrofit project.

Created on: 18. Jun 2022
Author: Hans Wilhelm Zeuschner

Bachelorarbeit:
	"Retrofit eines modernen
	Luftmassenmessers in einen Ottomotor
	mit Bosch L-Jetronic ECU unter
	Verwendung eines Mikrocontrollers"


Fachhochschule Emden/Leer

Studiengang:
Elektrotechnik im Praxisverbund
Sommersemester 2022
Bearbeitungszeitraum: 14.04.2022 bis 22.07.2022

Betreuer: Prof. Dr. Carsten Koch
Zweitprüfer: B. Eng. Ewald Zimmermann
*/

#include <Arduino.h>
#include <Wire.h>

#include "lmm_pins.h"
#include "lmm_basic_io.h"
#include "lmm_uart_config.h"
#include "lmm_dac_sig.h"
#include "lmm_digi_pot.h"
#include "lmm_config.h"
#include "lmm_electronic_sensor.h"

/*********************************************************************/
/**
 \brief Reads the temperature of the electronic sensor (HFM 5)
		Deprecated: no longer used since the NTC thermistor is connected directly

 \param	-

 \return  temperature in milli °C

 **********************************************************************/
uint16_t readEletrSensTemperatureMilliDegreeCelsius()
{
	uint16_t temperature = 0;
	uint16_t temperatureADCVal = 0;

	for (uint8_t i = 0; i < CONFIG_TEMPERATURE_AVG_COUNT; i++)
	{
		temperatureADCVal += analogRead(TEMP_SENSE_PIN);
	}
	temperatureADCVal = temperatureADCVal / CONFIG_TEMPERATURE_AVG_COUNT;

	if (temperatureADCVal == 0)
	{
		Serial.println(F("Thermistor doesn't seem to be connected."));
	}
	else
	{
		Serial.print("temperatureADCVal: ");
		Serial.println(temperatureADCVal);

		// Convert ADC value into temperature
		temperature = EL_SENSOR_TEMPERATURE_COEFF_X * temperatureADCVal + EL_SENSOR_TEMPERATURE_COEFF_OFFSET;

		Serial.print("temperature: ");
		Serial.println(temperature);
	}

	return temperature;
}

/*********************************************************************/
/**
 \brief Measures the analog output of the electronic sensor (HFM 5) (air mass passing through)

 \param		airADCVal ADC value (call by reference)

 \return  	-

 **********************************************************************/
void readElectrSensAir(uint16_t *airADCVal)
{
	*airADCVal = 0;
	for (uint16_t i = 0; i < CONFIG_AIR_SENS_AVG_COUNT; i++)
	{
		*airADCVal += analogRead(SIG_SENSE_PIN);
	}
	*airADCVal = *airADCVal / CONFIG_AIR_SENS_AVG_COUNT;
}
